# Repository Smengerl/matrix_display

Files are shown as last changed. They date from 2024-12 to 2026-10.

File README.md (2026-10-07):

# Multi-purpose low-cost matrix display





This project showcases a 32x8 pixel LED matrix display powered by an ESP32, designed for versatile applications such as clocks or smart home displays. Built on a budget of just $10, it uses 3D-printed parts and standard electronic components. Full source code and resources are provided to help you build it from scratch.

As an alternative to the code in this repository, ready-made firmware for this kind of display can be obtained from the [ESPTimeCast](https://github.com/mfactory-osaka/ESPTimeCast) project on GitHub.

## Table of Contents
- [Mechanics](#mechanics)
- [Electronics](#electronics)
- [Usage](#usage)
- [Acknowledgements](#acknowledgements)
- [Development](#development)
- [License](#license)
- [Authors](#authors)

Example use cases:
| Clock with NTP sync | Solar production panel for home assistant |
| --- | --- |
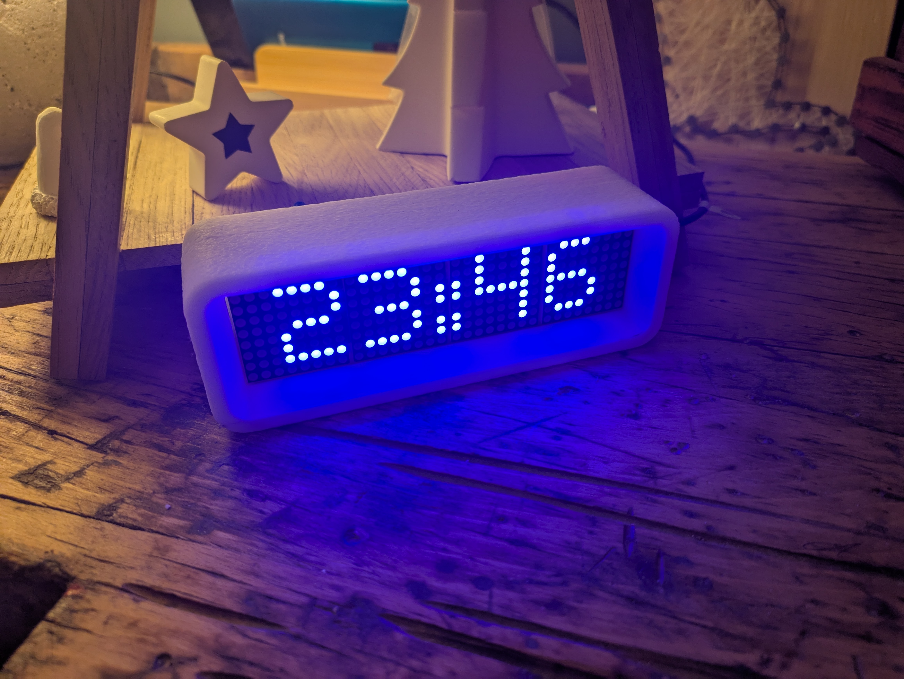
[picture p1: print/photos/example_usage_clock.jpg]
example_usage
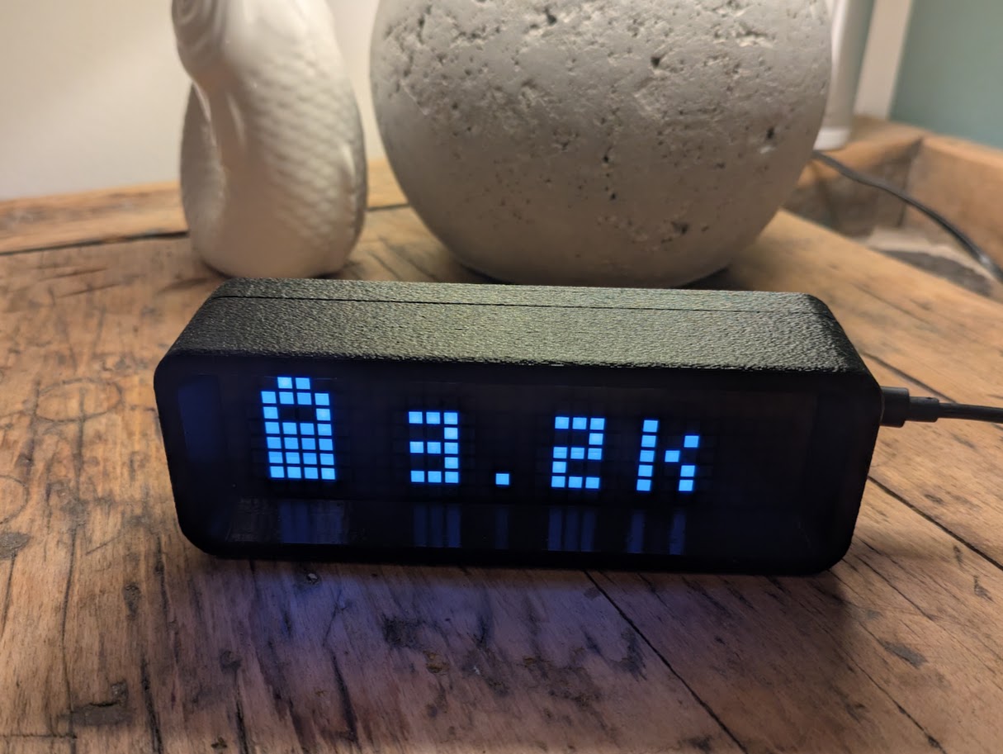
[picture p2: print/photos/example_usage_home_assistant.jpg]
example_usage
|||
| A standalone clock with an LED matrix display that automatically syncs time via NTP.<br><br>- Displays the current time in HH:MM format<br>- Customizable animations and dimming<br>- Automatic time synchronization using NTP | A multi-purpose Home Assistant display for various use cases, such as showing solar production and HEMS state.<br><br>- Home Assistant integration via ESPHome<br>- Displays arbitrary text<br>- Configurable parameters like fonts<br>- Integration with Home Assistant automation |
| [Go to Example](#clock-with-ntp-sync) | [Go to Example](#solar-production-control-panel-for-home-assistant) |

By experimenting with different filament colors, LED panels, and optional acrylic plates, you can create a variety of styles:
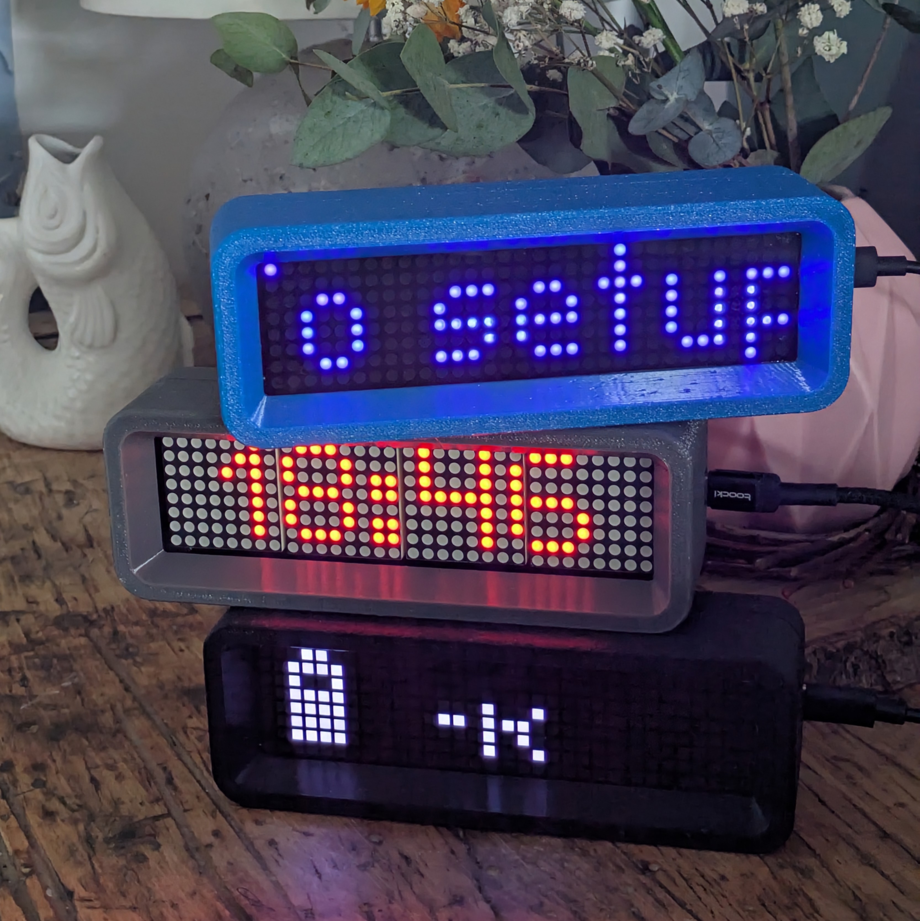
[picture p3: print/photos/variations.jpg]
variations


# Index
- [Mechanics](#Mechanics)
- [Electronics](#Electronics)
- [Usage: Clock with NTP sync](#clock-with-ntp-sync)
- [Usage: Generic home assistant display](#generic-home-assistant-display)
- [Usage: Solar production control panel for home assistant](#solar-production-control-panel-for-home-assistant)
- [Acknowledgements](#Acknowledgements)

## Mechanics

Renderings / Prototype:
| Front | Back | Isometric |
| --- | --- | --- |
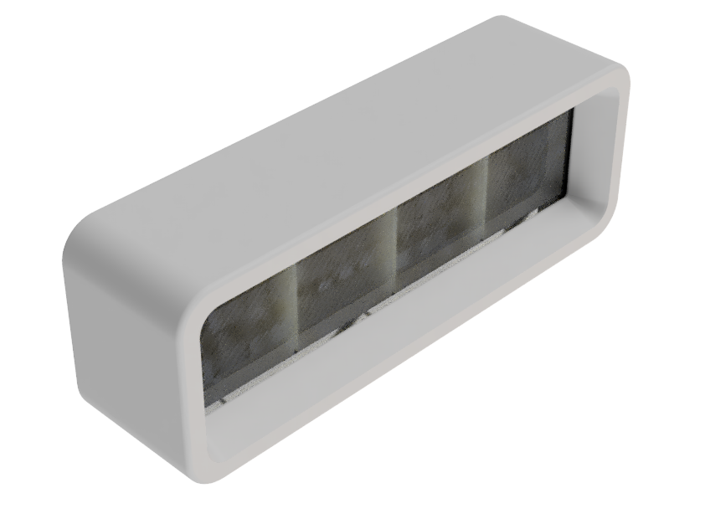
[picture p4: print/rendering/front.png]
front
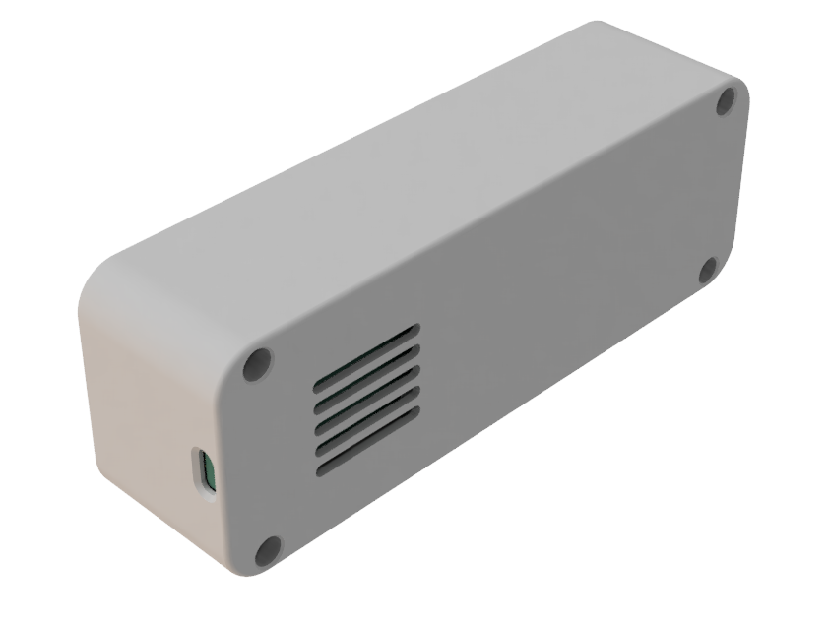
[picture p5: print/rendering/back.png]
back
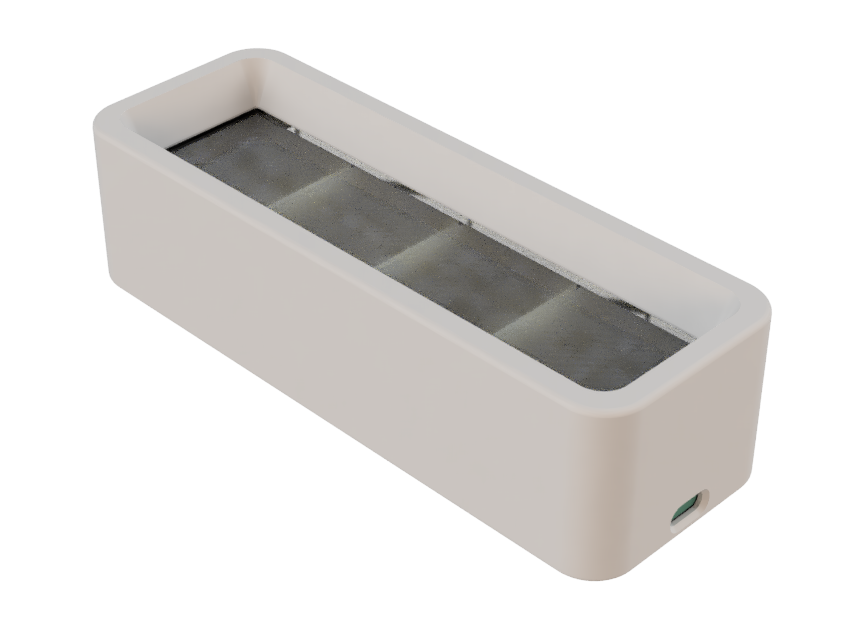
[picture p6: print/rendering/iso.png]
|  |  |  |
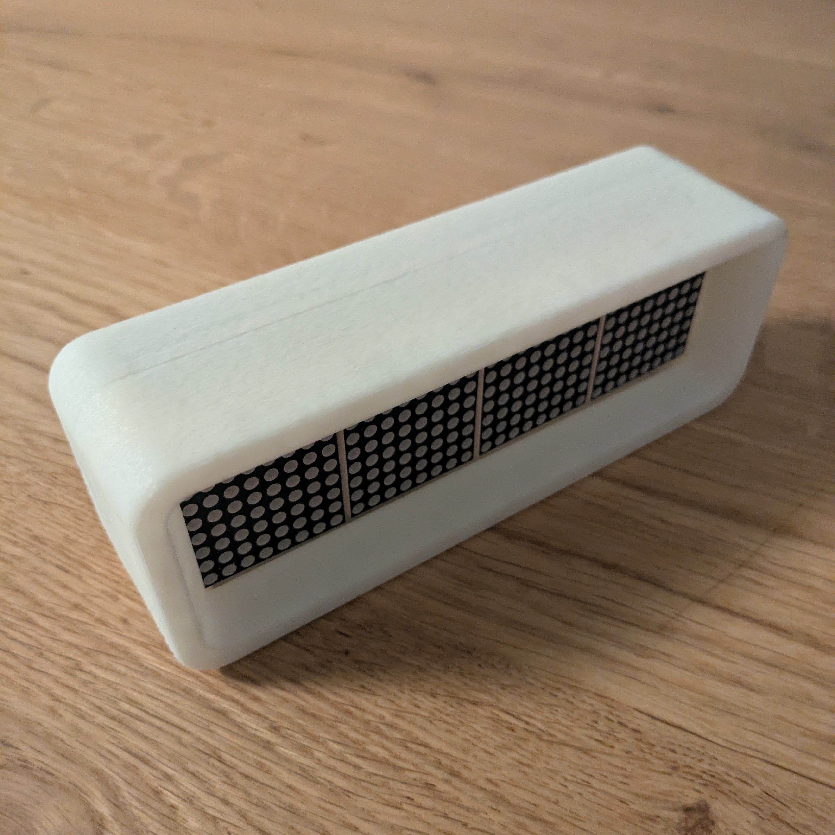
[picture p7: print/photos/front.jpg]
front
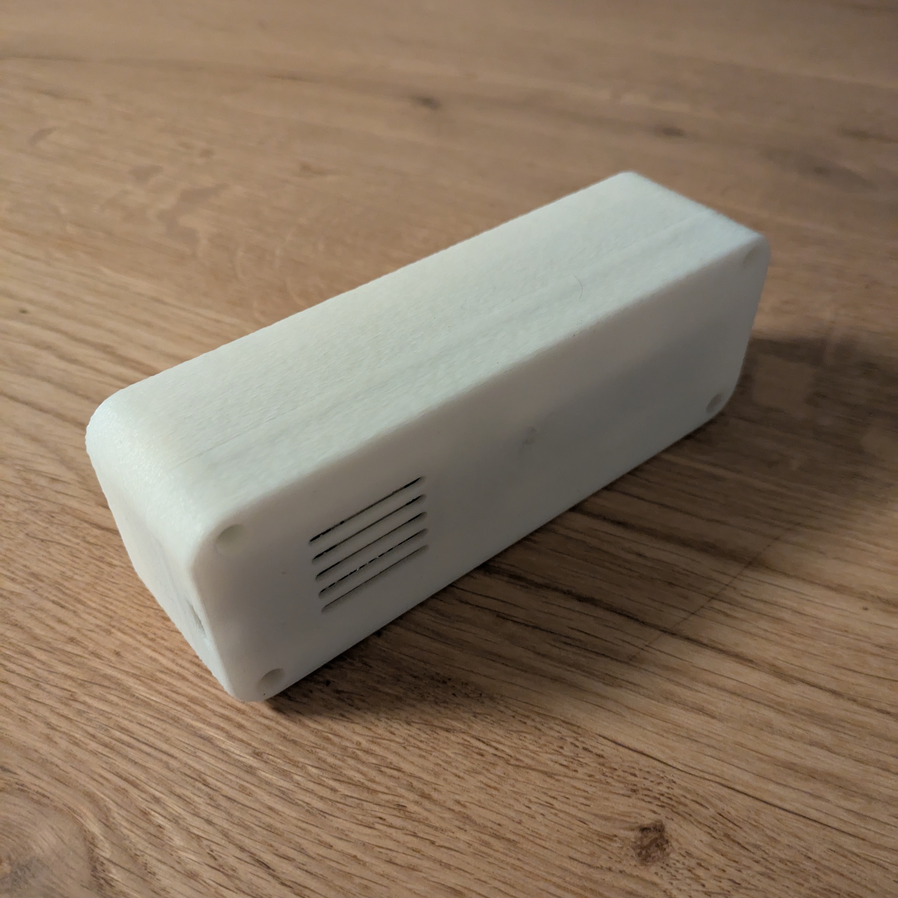
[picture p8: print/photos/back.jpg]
back
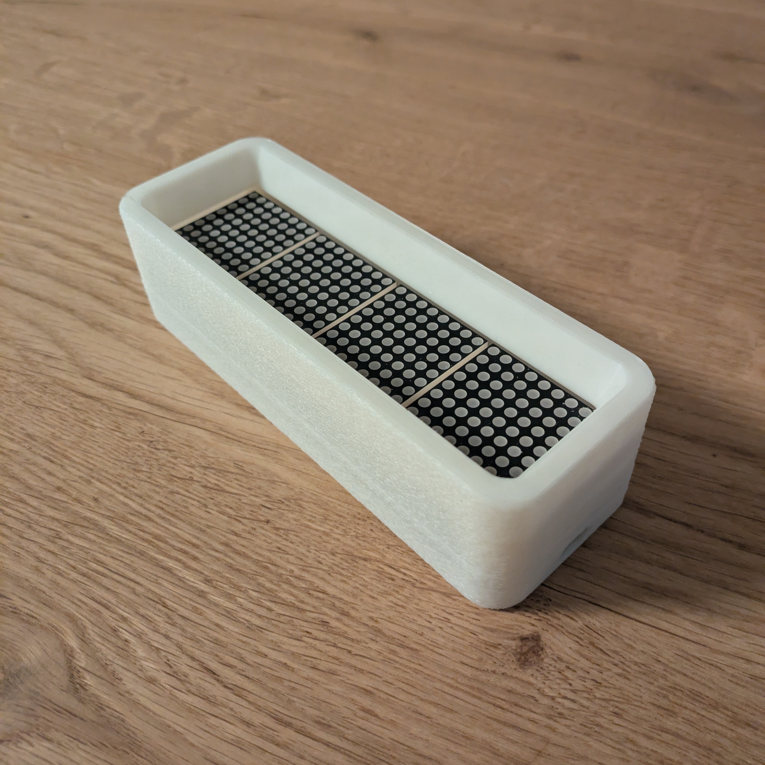
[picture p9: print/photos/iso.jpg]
|  |  |  |

The housing consists of a front and back piece, with an optional acrylic plate for a cleaner look (look for the difference in the example photos).

### 3D-Printed Parts

| Filename | Thumbnail | Required | Notes |
| --- | ---| --- | ---|
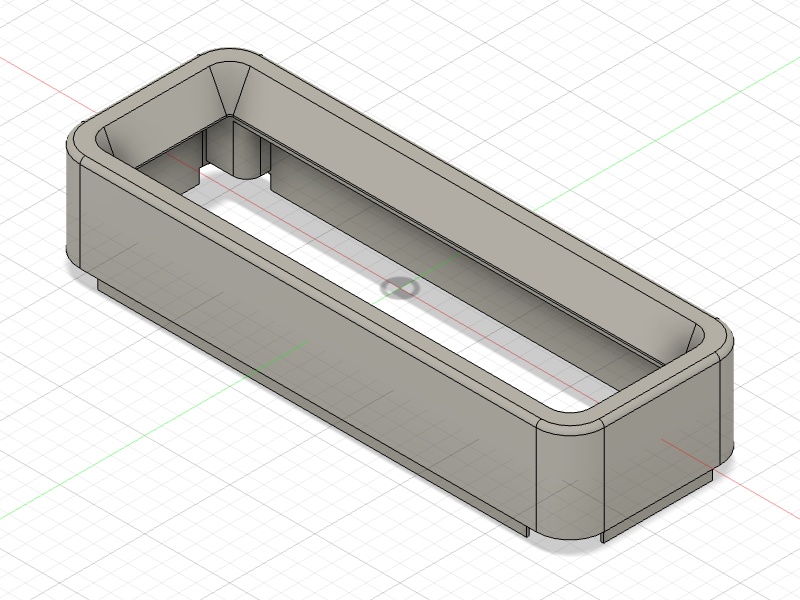
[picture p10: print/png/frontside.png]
frontside
| `./stl/frontside.stl` |  | 1 | |
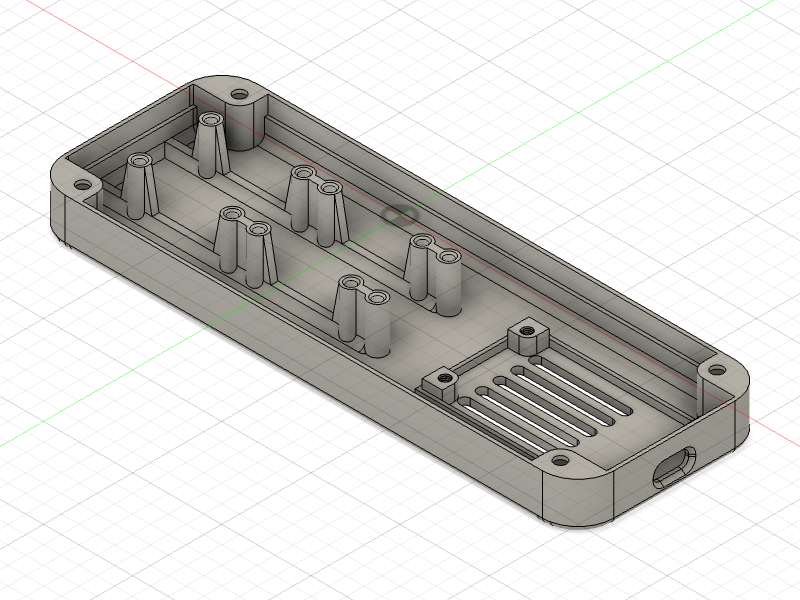
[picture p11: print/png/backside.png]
backside
| `./stl/backside.stl` |  | 1 | |

Printer settings:
- Material: PETG
- Recommended orientation: Print the front piece upside down (front facing the print bed) to avoid supports. For a cleaner look, print it reversed with ironing enabled, but note that this requires more support material.
- Use "fuzzy skin" for a nice texture on the outside walls.
- No rafts or brims are required.

### Required parts

| Name | Spec | Required | Notes |
| --- | --- | --- | ---|
| countersunk screw | M3 5mm (e.g. DIN EN ISO 4762)  | 4 | To attach ESP to housing |
| countersunk screw | M3 5mm (e.g. DIN EN ISO 4762)  | 4 | To attach display to the housing |
| cylinder head screw | M3 10mm | 4 | To secure the front and back pieces |
| semi-transparent acrylic board | max 2mm, 140-150mm * 33-35mm | 1 | Optional, for a cleaner look |

### Assembly

- Attach all electronics to the back of the housing using screws.
- Glue the acrylic plate to the front (optional).
- Snap the front and back pieces together and secure them with screws.
- Use hot glue if needed to ensure everything stays in place.

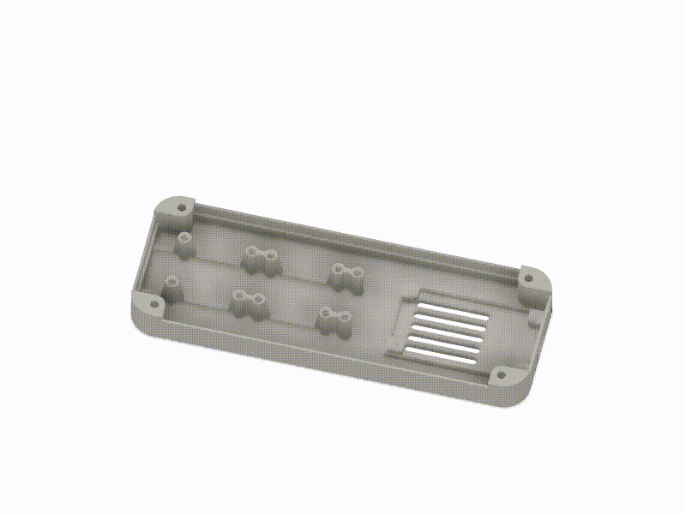
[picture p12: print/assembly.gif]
assembly


## Electronics

### Part list

| Unit price | Quantity | Partname | Example | Notes |
| --- | --- | --- | --- | ----- |
| 5 USD | 1 | ESP32 Dev module | <a href="https://de.aliexpress.com/item/1005006474308440.html">AliExpress</a> | USB-C Version |
| 3 USD | 1 | 4 digit 8x8 LED matrix display (MAX7219 FC16) | <a href="https://de.aliexpress.com/item/1005006976020684.html">AliExpress</a> |  |

Total cost: under 10 USD!

### Schematics

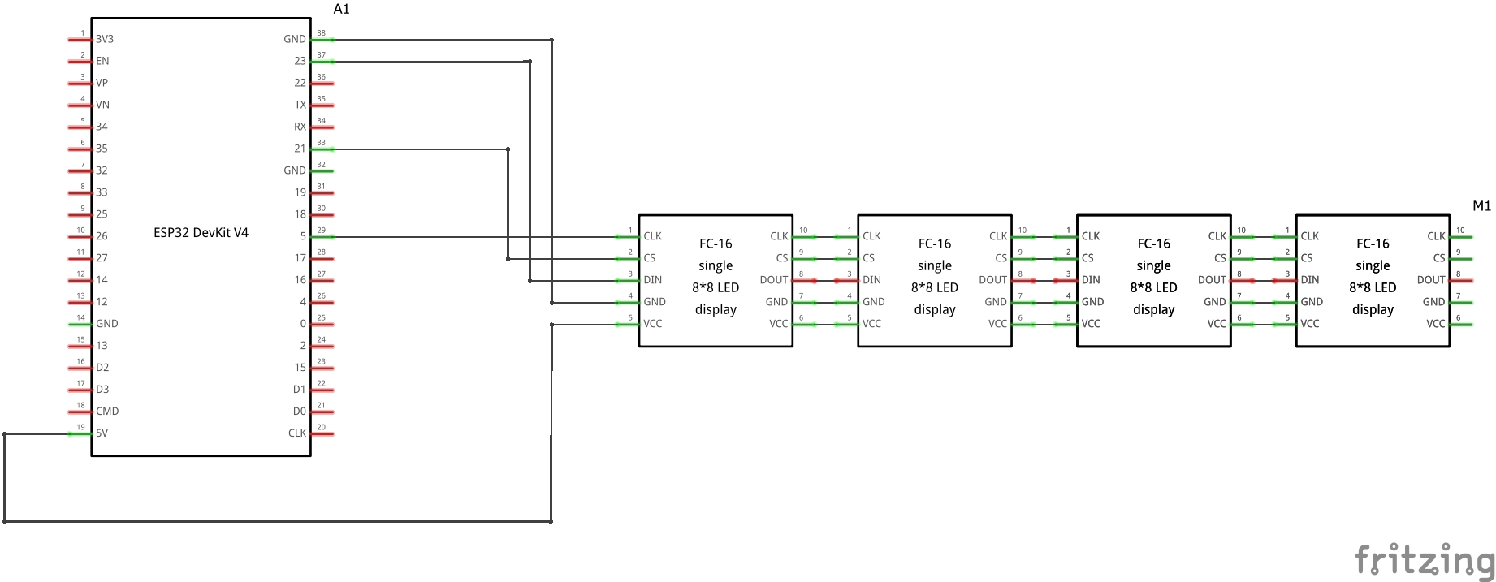
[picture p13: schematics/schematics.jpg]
schematics


## Usage

The display can be used for various applications. Below are some examples:

### Clock with NTP sync

A simple standalone application that syncs time via NTP and displays it on the LED matrix

#### Prerequisites

- PlatformIO
- MD_Parola (via PIO)
- ESPDateTime (via PIO) 
- WiFiManager (via PIO)

#### Installation

1. Clone the repository:
   ```sh
   git clone https://github.com/smengerl/Matrix_Clock.git
2. Open the project in PlatformIO.
3. Wait for PlatformIO to download the required libraries.
4. Compile and upload the project to your ESP32.

#### Usage
- Power on the ESP32.
- On first use, connect to the ESP32's access point and configure your WiFi credentials.
- Wait for NTP synchronization.
- The current time will be displayed on the LED matrix.

### Generic home assistant display

This example integrates the display with Home Assistant using ESPHome.

#### Prerequisites

- home assistant
- ESP home
- [ESPTimeCast](https://github.com/mfactory-osaka/ESPTimeCast) – firmware for ESP-based LED matrix clocks

#### Installation

1. Register the ESP32 with ESPHome (e.g., via ESPHome Web).
2. Rename the device to matrix-display (so that `matrix-display.yaml` is the .yaml of your ESP home configuration for the device)
3. Copy the contents of [./ha_scripts](././ha_scripts) to the folder `[homeassistant]/config/esphome`, replacing `matrix-display.yaml`
   - The config reads `wifi_ssid`, `wifi_password`, `matrix_display_api_key`, `matrix_display_ota_pw` and `matrix_display_fallback_pw` from `secrets.yaml`. Copy [`ha_scripts/secrets.yaml.example`](./ha_scripts/secrets.yaml.example) to `[homeassistant]/config/esphome/secrets.yaml` and fill in your own values (`secrets.yaml` is git-ignored).
4. Download the desired fonts and place them in the fonts subfolder. Fonts can be found at [1001fonts.com](https://www.1001fonts.com/pixel-fonts.html). Due to unclear licenses, I'm not sharing them here but you should not have any issue finding them by the name in the code on that page. If you want other fonts, you should have no issues adapting the code as all is in fonts.yaml and font_helper.h.
5. Customize `fonts.yaml` if needed, e.g. if you want to use further material-design icons than the one I had added as an example 
6. Open `matrix-display.yaml` in ESPHome and upload the configuration to the device.
7. Once installed, the device will appear in Home Assistant. Set up the device giving it a name (in the following I assume you called it again matrix_display) and you are ready to go. 

#### Usage

The device will show up in Home Assistant under the ESPHome integration.
<img src="./homeassistant_device_control_panel.jpg" alt="control_panel"/>

Use automations to update the display text based on events. For example, the following automation updates the display every minute:

```yaml
alias: Clock
description: ""
triggers:
  - trigger: time_pattern
    seconds: "0"
  - type: connected
    device_id: [YOUR DEVICE ID]
    entity_id: [YOUR ENTITY ID]
    domain: binary_sensor
    trigger: device
conditions: []
actions:
  - action: text.set_value
    metadata: {}
    data:
      value: "{{now().strftime('%H:%M')}}"
    target:
      entity_id: text.matrix_display_text_input
mode: single
```

### Solar production control panel for home assistant

This example displays solar production data and the state of your home energy management system (HEMS).

Features:
- Displays battery state of charge (SOC) as an icon.
- Shows whether energy is being imported or exported to the grid.
- Displays current solar production in kW.

```yaml
alias: Display solar production
description: ""
triggers:
  - entity_id: sensor.inverter_input_power
    trigger: state
  - entity_id: sensor.battery_state_of_capacity
    trigger: state
  - entity_id: sensor.power_meter_active_power
    trigger: state
  - type: connected
    device_id: [YOUR DEVICE ID]
    entity_id: [YOUR ENTITY ID]
    domain: binary_sensor
    trigger: device
conditions: []
actions:
  - variables:
      power_kw: >-
        {{ (states('sensor.inverter_input_power') | float(0) / 1000) | round(1)
        }}
      power_kw_s: |-
        {% if power_kw >= 1 %}
          {{ power_kw | round(1) | string }}k
        {% elif power_kw > 0 %}
          {{ power_kw | string | replace("0.", ".") }}k
        {% else %}
          -k
        {% endif %}
      active_power: "{{ states('sensor.power_meter_active_power') | int(0) }}"
      battery_level: "{{ states('sensor.battery_state_of_capacity') | int(0) }}"
      battery_power: "{{ states('sensor.battery_charge_discharge_power') | float(0) }}"
      mdi_icon: |-

        {% if active_power > 50 %}
          {{ "\U000F0F9C" }}
          {# mdi:home-import-outline (exporting to grid) #}

        {% elif active_power < -50 %}
          {{ "\U000F0D3E" }}
          {# mdi:import (importing from grid) #}

        {% else %}

          {% if battery_power > 0 %}
            {% if battery_level < 10 %}
              {{ "\U000F089F" }}
            {% elif battery_level < 20 %}
              {{ "\U000F089C" }}
            {% elif battery_level < 30 %}
              {{ "\U000F0086" }}
            {% elif battery_level < 40 %}
              {{ "\U000F0087" }}
            {% elif battery_level < 50 %}
              {{ "\U000F0088" }}
            {% elif battery_level < 60 %}
              {{ "\U000F089D" }}
            {% elif battery_level < 70 %}
              {{ "\U000F0089" }}
            {% elif battery_level < 80 %}
              {{ "\U000F089E" }}
            {% elif battery_level < 90 %}
              {{ "\U000F008A" }}
            {% elif battery_level < 100 %}
              {{ "\U000F008B" }}
            {% else %}
              {{ "\U000F0085" }}
            {% endif %}

          {% else %}

            {% if battery_level < 10 %}
              {{ "\U000F008E" }}
            {% elif battery_level < 20 %}
              {{ "\U000F007A" }}
            {% elif battery_level < 30 %}
              {{ "\U000F007B" }}
            {% elif battery_level < 40 %}
              {{ "\U000F007C" }}
            {% elif battery_level < 50 %}
              {{ "\U000F007D" }}
            {% elif battery_level < 60 %}
              {{ "\U000F007E" }}
            {% elif battery_level < 70 %}
              {{ "\U000F007F" }}
            {% elif battery_level < 80 %}
              {{ "\U000F0080" }}
            {% elif battery_level < 90 %}
              {{ "\U000F0081" }}
            {% elif battery_level < 100 %}
              {{ "\U000F0082" }}
            {% else %}
              {{ "\U000F0079" }}
            {% endif %}

          {% endif %}

        {% endif %}
  - if:
      - condition: template
        value_template: "{{ active_power > 50 }}"
    then:
      - action: text.set_value
        metadata: {}
        data:
          value: "{{ mdi_icon }} {{ power_kw_s }}"
        target:
          entity_id: text.matrix_display_text_input
    else:
      - action: text.set_value
        metadata: {}
        data:
          value: "{{ mdi_icon }} {{ power_kw_s }}"
        target:
          entity_id: text.matrix_display_text_input
mode: single
```

## Acknowledgements
- MD_Parola library by MajicDesigns
- home assistant
- ESP home

## Development

Contributions are welcome.  
See `CONTRIBUTING.md` for details and follow the `CODE_OF_CONDUCT.md` when contributing.

All .stl, .png, and assembly pictures are automatically exported via my Fusion add-in, see [here](https://github.com/smengerl/fusion-exporter)

## License

This project is licensed under the Creative Commons Attribution-ShareAlike 4.0 International License (CC BY-SA 4.0) — see `LICENSE.txt` for details or visit http://creativecommons.org/licenses/by-sa/4.0/

## Authors

- Simon Gerlach <https://github.com/Smenger>

---

If something in this README is missing or unclear, please open an issue in the repository so the instructions can be improved.

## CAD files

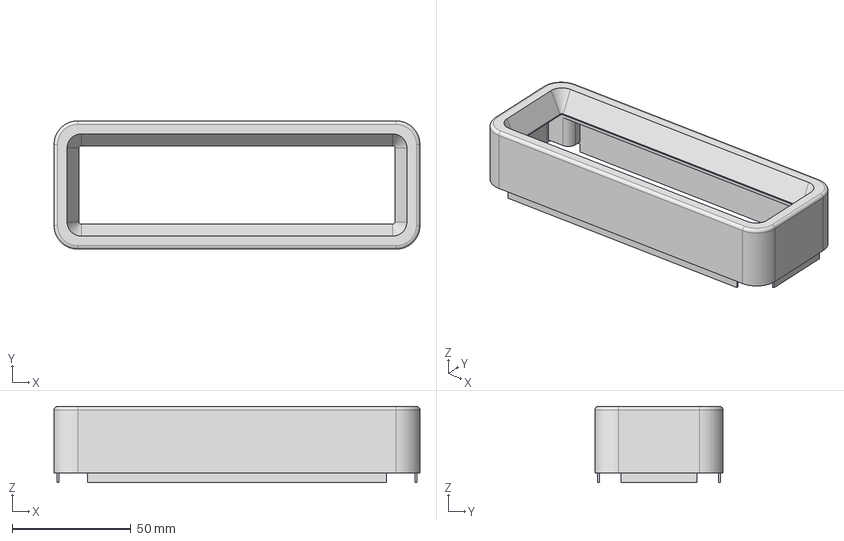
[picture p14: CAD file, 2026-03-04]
print/step/frontside.step
154.0 x 54.0 x 32.0 mm

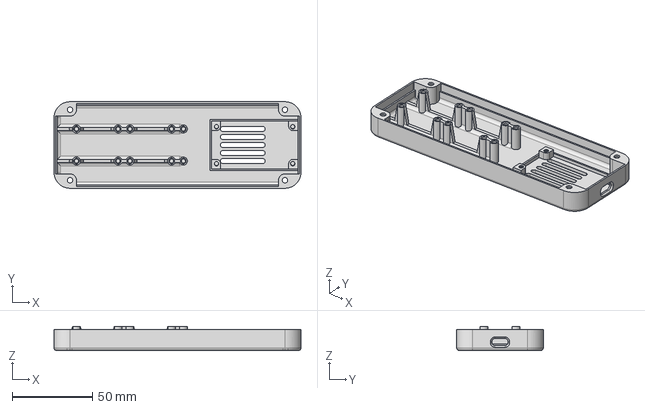
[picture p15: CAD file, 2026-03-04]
print/step/backside.step
154.0 x 54.0 x 15.0 mm

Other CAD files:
print/fusion_export.f3z
print/stl/backside.stl
print/stl/frontside.stl

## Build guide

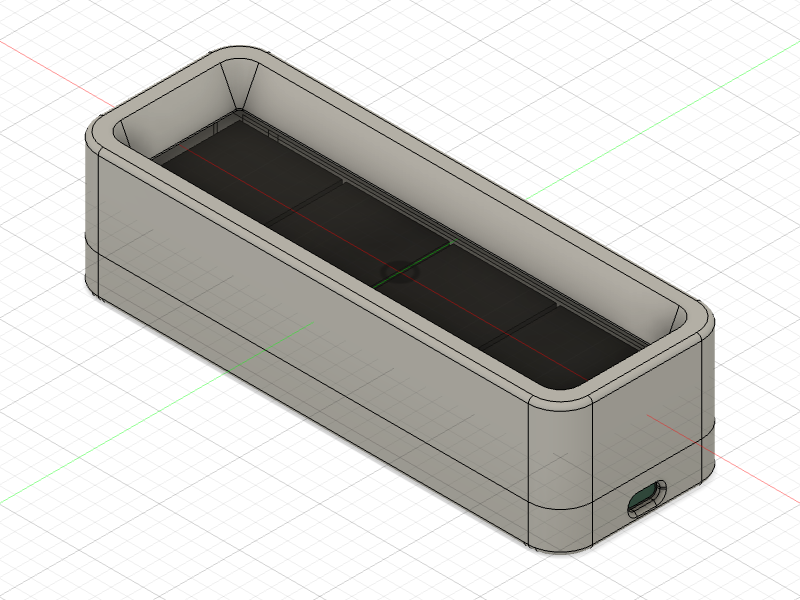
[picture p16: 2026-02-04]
print/zsb/full.png

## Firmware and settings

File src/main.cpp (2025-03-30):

/*
 * LED Matrix clock based on ESP32 with Wifi+NTP sync
 */
#include <MD_Parola.h>
#include <MD_MAX72xx.h>
#include <WiFiManager.h>
#include <WiFi.h>
#include "ESPDateTime.h"
#include "config.h"
#include "esp_bt.h"

#include <freertos/FreeRTOS.h>
#include <freertos/task.h>
#include <freertos/semphr.h>

// ***********************************************************
// NTP SETTINGS
// ***********************************************************

/** Servername of NTP server to use to get the time from */
#define NTP_SERVER "pool.ntp.org" 

/** Which timezone we are in */
#define TIMEZONE "CET-1CEST,M3.5.0,M10.5.0/3" 

/** Max roundtrip time for NTP sync in ms */
#define NTP_SYNC_TIMEOUT 15000


// ***********************************************************
// DISPLAY SETTINGS
// ***********************************************************
// LED matrix intensity from 0...0x0f (brightest)
#define LED_INTENSITY 0x00
// LED matrix inverted?
#define INVERT false

// Animation for old time to disappear
#define OUT_ANIMATION_SPEED 50
#define OUT_ANIMATION_MODE PA_SCROLL_UP

// Animaton for new time to appear
#define IN_ANIMATION_SPEED 50
#define IN_ANIMATION_MODE PA_SCROLL_UP

// Animation for all messages to user on display
#define DEFAULT_ANIMATION_SPEED 50
#define DEFAULT_ANIMATION_STOP 1500


// ***********************************************************
// HW SETTINGS
// ***********************************************************
// GPIO-Pins on ESP32 for LED Matrix
#define PIN_NUM_MOSI GPIO_NUM_23 /** Pin on ESP for MOSI signal to LED Matrix */
#define PIN_NUM_CLK  GPIO_NUM_5  /** Pin on ESP for CLK signal to LED Matrix */
#define PIN_NUM_CS   GPIO_NUM_21 /** Pin on ESP for CS signal to LED Matrix */

// HW setup LED matrix
#define HARDWARE_TYPE MD_MAX72XX::FC16_HW /** Hardware type of LED matrix display */
#define MAX7219_NUM_DEVICES 4 /** Number of daisy-chained LED matrix display elements */





MD_Parola* ledMatrix;




void setupMatrixDisplay() {
  // initialize the object
  ledMatrix = new MD_Parola(HARDWARE_TYPE, PIN_NUM_MOSI, PIN_NUM_CLK, PIN_NUM_CS, MAX7219_NUM_DEVICES);
  ledMatrix->begin();         
  ledMatrix->setIntensity(LED_INTENSITY); // set the brightness of the LED matrix display (from 0 to 15)
  ledMatrix->setInvert(INVERT);
  ledMatrix->displayClear();  // clear led matrix display
}




SemaphoreHandle_t ntpSyncSemaphore = NULL;

void DateTimeTask(void *pvParameters) {
  
  Serial.print("NTP synching, please wait... ");

  DateTime.setServer(NTP_SERVER);
  DateTime.setTimeZone(TIMEZONE);

  while (!DateTime.begin(NTP_SYNC_TIMEOUT)) {
    Serial.print("Timeout, retrying\n");
  }
  Serial.println("done");

  Serial.printf("Date Now is %s\n", DateTime.toISOString().c_str());
  Serial.printf("Timestamp is %ld\n", DateTime.now());

  xSemaphoreGive(ntpSyncSemaphore); // Give the semaphore to signal task completion
  vTaskDelete(NULL); // Delete this task when done
}

void setupDateTime() {
  ledMatrix->displayText("NTP Sync", PA_CENTER, DEFAULT_ANIMATION_SPEED, DEFAULT_ANIMATION_STOP, PA_SCROLL_LEFT, PA_FADE);

  ntpSyncSemaphore = xSemaphoreCreateBinary(); // Create the semaphore
  xTaskCreate(
    DateTimeTask, // Task function
    "NTPSync",    // Name of the task
    4096,         // Stack size (in words)
    NULL,         // Task input parameter
    1,            // Priority of the task
    NULL          // Task handle
  );

  while (!xSemaphoreTake(ntpSyncSemaphore, pdMS_TO_TICKS(DEFAULT_ANIMATION_SPEED))) { // Check if sync is already complete, max wait time is the time for an animation frame
    Serial.print(".");
    if (ledMatrix->displayAnimate()) {
      ledMatrix->displayReset();
    }
  }
  vSemaphoreDelete(ntpSyncSemaphore); // Delete the semaphore
}


void setupWiFi() {
  //WiFiManager, Local variable sufficient as once its business is done, there is no need to keep it any longer
  WiFiManager wm;

  Serial.println("WiFi connecting... ");

  char buf[100];
  snprintf(buf, sizeof(buf), "To setup Wifi connect to: %s", wm.getDefaultAPName().c_str());
  ledMatrix->displayText(buf, PA_CENTER, DEFAULT_ANIMATION_SPEED, DEFAULT_ANIMATION_STOP, PA_SCROLL_LEFT, PA_FADE);

  // reset settings - wipe stored credentials for testing
  // these are stored by the esp library
  // wm.resetSettings();

  wm.setConfigPortalBlocking(false); // asynchroneous mode in order to display the message on the LED matrix
  if (!wm.autoConnect()) { // Try to reconnect to last WiFi or open non password protected AP with default name
    while (!wm.process()) {
      if (ledMatrix->displayAnimate()) {
        ledMatrix->displayReset();
      }
      Serial.print(".");
    }
    Serial.println("WiFi successfully connected (using manual config in AP portal)");
  } else {
    Serial.println("WiFi successfully connected (using saved credentials)");
  }
}

void disableWiFi() {
  WiFi.disconnect(true);
  WiFi.mode(WIFI_OFF);
  Serial.println("WiFi disabled");
}

// Function to disable Bluetooth
void disableBluetooth() {
  if (esp_bt_controller_get_status() == ESP_BT_CONTROLLER_STATUS_ENABLED) {
      esp_err_t ret = esp_bt_controller_disable();
      if (ret != ESP_OK) {
          Serial.printf("Bluetooth disable failed: %s\n", esp_err_to_name(ret));
          return;
      }
  }

  if (esp_bt_controller_get_status() == ESP_BT_CONTROLLER_STATUS_INITED) {
      esp_err_t ret = esp_bt_controller_deinit();
      if (ret != ESP_OK) {
          Serial.printf("Bluetooth deinit failed: %s\n", esp_err_to_name(ret));
          return;
      }
  }

  Serial.println("Bluetooth disabled");
}


void setup() {
  Serial.begin(115200);

  disableBluetooth();

  setupMatrixDisplay();

  // Sync with NTP only on initial startup. After that, power off Wifi to save energy
  setupWiFi();
  setupDateTime();
  disableWiFi();
}





void sleepForNextMinute() {
  // Sleep until next full minute
  time_t now = DateTime.now();
  struct tm *tm = localtime(&now);
  long sleepTime = (60 - tm->tm_sec) * 1000; // ms

  // Implement deep sleep functionality here
  Serial.printf("\nEntering sleep for %dms...\n", sleepTime);

  // Advise FreeRTOS to wait for up to this amount of time
  vTaskDelay(pdMS_TO_TICKS(sleepTime));

// Using deep sleep requires some rework as all initialization would need to be redone and setup routine is called again on wakeup
//  esp_sleep_enable_timer_wakeup( * 1000);
//  esp_deep_sleep_start();
}


int lastMin = -1;
int lastHour = -1;
char time_str[20] = ""; // HH:MM format


void loop() {
  time_t now = DateTime.now();
  struct tm *tm = localtime(&now);

  // Adjust for daylight saving time if necessary
  //if (tm->tm_isdst > 0) {
  //  tm->tm_hour += 1;
  //  mktime(tm); // Normalize the time structure
  //}


  if (tm->tm_min != lastMin || tm->tm_hour != lastHour ) {
    lastMin = tm->tm_min;
    lastHour = tm->tm_hour;

    ledMatrix->displayText(time_str, PA_CENTER, OUT_ANIMATION_SPEED, 0, PA_NO_EFFECT, OUT_ANIMATION_MODE);
    Serial.print("\nOut animation");
    do {
      Serial.print(".");
    } while (!ledMatrix->displayAnimate());


    strftime(time_str, sizeof(time_str), "%H:%M", tm);
    Serial.printf("\nCurrent time: %s", time_str);

    ledMatrix->displayText(time_str, PA_CENTER, IN_ANIMATION_SPEED, 0, IN_ANIMATION_MODE, PA_NO_EFFECT);
    Serial.print("\nIn animation");
    do {
      Serial.print(".");
    } while (!ledMatrix->displayAnimate());

  } else {
    Serial.print("Loop function called but no further minute has passed. Is sleep cycle correctly configured?\n");
  }

  sleepForNextMinute();
}

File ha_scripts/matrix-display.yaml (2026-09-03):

substitutions:
  name: "matrix-display"
  friendly_name: Matrix LED Display
  comment: Multi purpose matrix LED display
  project_name: matrix_led_display.esphome

  TAG: "matrix-led-display.yaml"




  api_key: !secret matrix_display_api_key
  ota_pw: !secret matrix_display_ota_pw
  fallback_hotspot_ssid: "Matrix Display Fallback Hotspot"
  fallback_hotspot_pw: !secret matrix_display_fallback_pw



packages:
  device_basics: !include matrix_display_packages/device_basics.yaml
  debug_basics: !include shared_packages/debug_basics.yaml
  fonts: !include matrix_display_packages/fonts.yaml







esphome:
  name: ${name}
  friendly_name: ${friendly_name}
  comment: ${comment}
  min_version: "2026.8.1"
  name_add_mac_suffix: false
  project:
    name: ${project_name}
    version: '1.0'
  compile_process_limit: 1
  includes:
    - ./matrix_display_packages/font_helper.h

  on_boot:
    - priority: -100  # Initialization should be completely done here
      then:
        - lambda: |-
            id(boot_completed) = true;
            id(update_scrolling).execute();
            id(update_brightness).execute();
            id(trigger_rendering).execute();



globals:
  - id: boot_completed
    type: bool
    restore_value: no
    initial_value: "false"




# ******************************************************************************
# Render loop
# ******************************************************************************

# https://esphome.io/components/display/max7219digit.html
display:
  - platform: max7219digit
    id: led_display
    cs_pin: $cs_pin
    num_chips: $num_chips
    update_interval: 1s   # renders itself -> $offline shows on WiFi loss, missed content updates self-heal
    lambda: |-
      // id(wifi_id) is a reference to a statically-allocated component - never
      // null, so no nullptr check (it triggered -Waddress).
      if(id(wifi_id).is_connected()) {

        auto font_index = id(font_select).active_index();
        esphome::font::Font* font = id($default_font_id); // default font
        int deltaY = 0;


        if (font_index.has_value()) {
          int index = font_index.value();

          if (!getFontBySelectId(index, &font, &deltaY)) {
            ESP_LOGW("$TAG", "Undefined font index. Using default.");
          }
        } else {
          ESP_LOGW("$TAG", "Cannot determine selected font. Using default.");
        }

        deltaY += id(verticalPos).state;

        bool scroll_enable = id(scrolling).state;
        bool text_centered = false;
        if (!scroll_enable) {
          text_centered = id(centered).state;
        }


        std::string msg = id(lcd_text).state;
        //const char* font_string = id(font_select).state.c_str();
        //ESP_LOGI("$TAG", "Printing [%s] in font %d / %s", msg.c_str(), font_index, font_string);
        
        if (text_centered) {
          it.print(it.get_width() / 2, it.get_height() / 2 + deltaY, font, TextAlign::CENTER, msg.c_str());
        } else {
          it.print(0, it.get_height() / 2 + deltaY, font, TextAlign::CENTER_LEFT, msg.c_str());
        }

      } else {
        ESP_LOGD("$TAG", "Wifi not connected");
        it.print(it.get_width() / 2, it.get_height() / 2, id(icon_font), TextAlign::CENTER, "$offline");
      }




# ******************************************************************************
# Scripts
# ******************************************************************************
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

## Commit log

2024-12-28 Added 3D models and renderings
    [back.stl, front.stl]
2024-12-28 Uploaded assembly video
2024-12-28 Removed unecessary dependency, adapted serial monitor baudrate and fixed NTP synching timing bug
    [main.cpp]
2024-12-29 Some power optimizations (WiFi/BT disabling, improved sleep cycle)
2024-12-29 Added better renderings, added acrylic plate
2024-12-29 Added photos. updated stl files. Added full fusion export
    [back.stl, backside.stl, front.stl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]
2024-12-30 Bugfix in model due to wrong spacing of screw connection
    [backside.stl, frontside.stl, fusion_export.f3z]
2025-01-01 NTP sync now in separate thread
2025-01-02 Added schematis/wiring diagram
    [schematics.fzz]
2025-01-19 Fixed wrong screw in readme
2025-03-30 Fixed some compiler warnings
    [matrix-display.yaml]
2025-03-30 Fixed dailight saving time bug
    [main.cpp]
2025-11-26 suppressing strapping pin warnings
2026-02-04 Moved files to standard folder structure of exporter plugin
    [backside.stl, frontside.stl]
2026-02-04 Fresh fusion export by plugin
    [backside.stl, frontside.stl]
2026-02-04 Full export of latest exportable version for plugin
    [fusion_export.f3z]
2026-02-17 Update license information to Creative Commons Attribution-ShareAlike 4.0 in LICENSE.txt and README.md
    [fusion_export.f3z]
2026-03-04 Added full fusion export and STEP exports to enable remixing
    [backside.step, frontside.step, fusion_export.f3z]
2026-03-04 Add .DS_Store and print/.DS_Store to .gitignore to prevent unnecessary file tracking
2026-09-01 Port ESPHome config-review fixes: remove display mutex, self-rendering update_interval
    - Remove the FreeRTOS mutex (mutex_helper.h + init/lock/unlock wrappers). It
    guarded nothing (single main-loop task) and a failed lock silently dropped
    scroll/brightness/render updates.
    - display update_interval: never -> 1s so max7219 re-renders itself: $offline
    shows on WiFi loss and missed content updates self-heal.
    - lcd_text: drop restore_value (HA writes it ~1x/min -> flash wear).
    - 'Wifi not connected' render log ESP_LOGW -> ESP_LOGD (fires every second now).
    [matrix-display.yaml]
2026-09-01 Review follow-ups: align with local source
    - device_basics.yaml: drop dashboard_import import_full_config: true (missed
    in the earlier cruft cleanup; already removed from ePaper).
    - matrix-display.yaml: fix identifiers copied from the color-matrix repo
    (project_name/TAG/fallback_hotspot_ssid -> matrix-led-display).
    - matrix-display.yaml + font_helper.h: adopt the local font-selection path
    (getFontBySelectId takes Font** so the selected font actually applies;
    public passed Font* by value -> selection had no effect).
    - matrix-display.yaml: match local logging in the 3 scripts (early-return +
    ESP_LOGD for 'skipped, still booting', 'brightness changed to %d').
    - shared_packages/debug_b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
    [matrix-display.yaml]
2026-09-03 Sync from home config: min_version, font-select cleanup, -Waddress fix
    - esphome.min_version: "2026.8.1"
    - font_select options: fix "origa___.ttf &6 px)" typo, normalise casing/
    spacing (labels are cosmetic - font_select uses active_index()), add a note
    that their order must match font_helper.h
    - display lambda: drop the "id(wifi_id) != nullptr" guard - id() resolves to a
    statically-allocated component reference that is never null, which triggered
    a compiler warning (the address ... will never be NULL [-Waddress])
    [matrix-display.yaml]
